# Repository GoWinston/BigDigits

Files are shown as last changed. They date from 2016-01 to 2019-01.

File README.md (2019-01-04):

# The Big Board

This is an Arduino powered system to allow the construction of giant seven segment displays, up to 50V 0.5A per segment.

The library workes with any Arduino using the SPI protocol, allowing a 4 digit display (32 segements) to be remotely connected via a single ethernet cable.

Two PCB designs are included, one with four digits on one board and another with a single digit per board.  

The hardware and library support four channels. 

<hr>

Boards are availible at OshPark <br>
4 Channel: https://oshpark.com/shared_projects/9ZOlH1Lw <br>
Digikey parts list [here](https://github.com/GoWinston/BigDigits/blob/master/PCB's/4%20Digit%20PCB%20Materials%20Digikey.csv)<br>
<br>
1 Channel: https://oshpark.com/shared_projects/VTMd3b0f <br>
Digikey parts list [here](https://github.com/GoWinston/BigDigits/blob/master/PCB's/1%20Digit%20PCB%20Materials%20Digikey.csv)<br>

<hr>

Connect to the Arduino with a standard ethernet cable and the SparkFun RJ45 Breakout <br>
https://www.sparkfun.com/products/716 <br>
<br>
```
Ethernet | Arduino | Assignment
    1         13      Clock - SCK - SHCP
    2         11      Data - MOSI - DS
    3         9       Digit D  X---  Thousands
    4         6       Digit A  ---X  Units
    5         8       Digit C  -X--  Hundreds
    6         7       Digit B  --X-  Tens
    7         +5      VCC
    8         GND     GND
```
<hr>

The power for the big displays goes directly into the PCBs and is seperate from the logic power on the Arduino which travels over the ethernet cable<br>
<br>
Power each segement from V+ --> LED segment lights --> Control Board <br>
<hr>

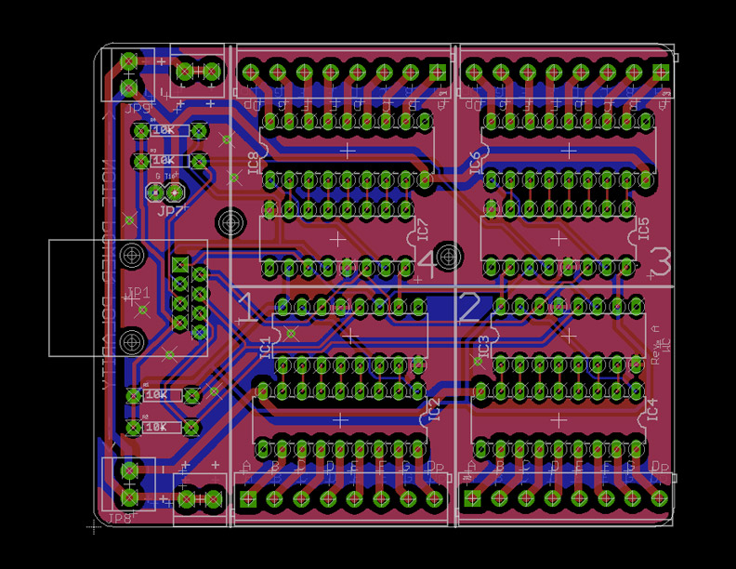
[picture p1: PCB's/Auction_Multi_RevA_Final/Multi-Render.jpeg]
4 channel board


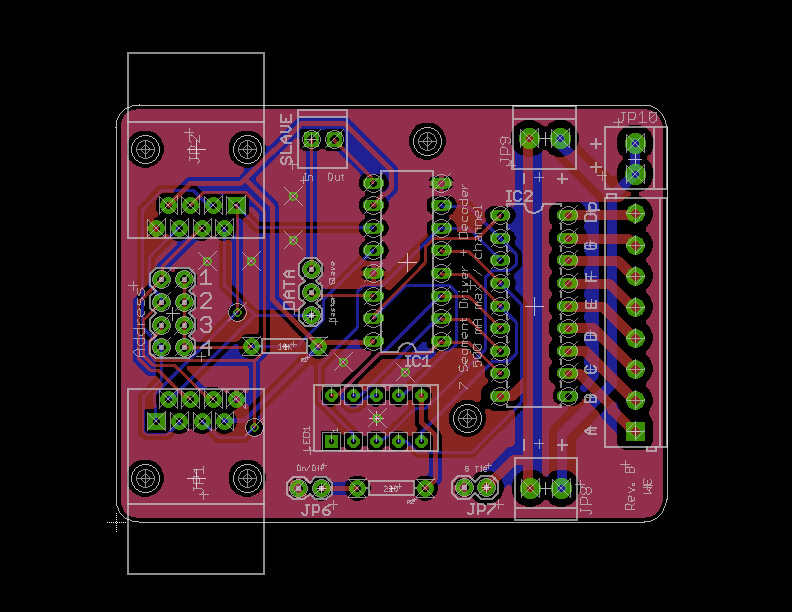
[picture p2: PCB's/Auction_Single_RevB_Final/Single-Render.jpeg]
1 channel board


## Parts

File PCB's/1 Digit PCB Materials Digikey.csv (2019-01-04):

Manufacturer Part Number | Manufacturer | Digi-Key Part Number | Customer Reference | Reference Designator | Packaging | Part Status | Quantity | Unit Price | Extended Price | Quantity Available | Mfg Std Lead Time | Description | RoHS Status | Lead Free Status | REACH Status | US Tariff Status
SN74HC595N | Texas Instruments | 296-1600-5-ND | IC1 |  | Tube | Active | 1 | 0.53000 | $0.53 | 27007 | 8 Weeks | IC 8-BIT SHIFT REGISTER 16-DIP | RoHS Compliant | Lead free | REACH Unaffected
ULN2803A | STMicroelectronics | 497-2356-5-ND | IC2 |  | Tube | Active | 1 | 1.19000 | $1.19 | 48108 | 28 Weeks | TRANS 8NPN DARL 50V 0.5A 18DIP | RoHS Compliant | Lead free | Not Available
CFR-25JB-52-10K | Yageo | 10KQBK-ND | 10k Resistor |  | Bulk | Active | 1 | 0.10000 | $0.10 | 395176 | 16 Weeks | RES 10K OHM 1/4W 5% AXIAL | RoHS Compliant | Lead free | REACH Unaffected
54602-908LF | Amphenol ICC (FCI) | 609-1046-ND | Ethernet Jack |  | Bulk | Active | 2 | 0.60000 | $1.20 | 101891 | 6 Weeks | CONN MOD JACK 8P8C R/A UNSHLD | RoHS Compliant | Lead free | Not Available
PH2-230/120-081 | On Shore Technology Inc. | PH2-230/120-081-ND | Address Selector |  | Bulk | Active | 1 | 0.40000 | $0.40 | 26 | 12 Weeks | CONN HEADER VERT 8POS 2.54MM | RoHS Compliant | Lead free | REACH Unaffected | Tariff Applied
61300311121 | Wurth Electronics Inc. | 732-5316-ND | Slave Master Selector |  | Bag | Active | 1 | 0.13000 | $0.13 | 142616 | 14 Weeks | CONN HEADER VERT 3POS 2.54MM | RoHS Compliant | Lead free | REACH Unaffected
282834-2 | TE Connectivity AMP Connectors | A98333-ND | Selector Pins Display Ground Tie |  | Box | Active | 2 | 0.88000 | $1.76 | 28602 | 21 Weeks | TERM BLK 2P SIDE ENT 2.54MM PCB | RoHS Compliant | Lead free | Not Available
382811-8 | TE Connectivity AMP Connectors | A26228-ND | Shunts for pins |  | Bulk | Active | 4 | 0.00000 | $0.00 | 57180 | 4 Weeks | CONN SHUNT 2POS OPEN 2.54MM | RoHS Compliant | Lead free | Not Available
HDSP-C3E3 | Broadcom Limited | 516-3177-5-ND | Seven Segment Display |  | Tube | Active | 1 | 0.00000 | $0.00 | 0 | 12 Weeks | DISPLAY 0.36 SGL DGT CC RED TH | RoHS Compliant | Lead free | REACH Unaffected | Tariff Applied
OSTTE080104 | On Shore Technology Inc. | ED2746-ND | Display Segment Connectors (optional) |  | Bulk | Active | 1 | 1.64000 | $1.64 | 7452 | 12 Weeks | TERM BLK 8POS SIDE ENT 3.5MM PCB | RoHS Compliant | Lead free | REACH Unaffected | Tariff Applied
1984617 | Phoenix Contact | 277-1721-ND | Power Connectors (optional) |  | Box | Active | 3 | 0.48000 | $1.44 | 72569 | 4 Weeks | TERM BLK 2POS SIDE ENT 3.5MM PCB | RoHS Compliant | Lead free | Not Available
A 16-LC-TT | Assmann WSW Components | AE9992-ND | Sockets for SHIFT REGISTER (optional) |  | Tube | Active | 1 | 0.25000 | $0.25 | 46264 | 20 Weeks | CONN IC DIP SOCKET 16POS TIN | RoHS Compliant | Lead free | REACH Unaffected | Tariff Eligible
ED18DT | On Shore Technology Inc. | ED3047-5-ND | Socket for ULN2803A (optional no high current) |  | Tube | Active | 1 | 0.23000 | $0.23 | 12504 | 12 Weeks | CONN IC DIP SOCKET 18POS TIN | RoHS Compliant | Lead free | REACH Unaffected | Tariff Applied
282834-2 | TE Connectivity AMP Connectors | A98333-ND | Connector for Slave Data Input (optional) |  | Box | Active | 1 | 0.88000 | $0.88 | 28602 | 21 Weeks | TERM BLK 2P SIDE ENT 2.54MM PCB | RoHS Compliant | Lead free | Not Available
CFR-25JB-52-220R | Yageo | 220QBK-ND | 220ohm for micro display |  | Bulk | Active | 1 | 0.10000 | $0.10 | 144243 | 16 Weeks | RES 220 OHM 1/4W 5% AXIAL | RoHS Compliant | Lead free | REACH Unaffected

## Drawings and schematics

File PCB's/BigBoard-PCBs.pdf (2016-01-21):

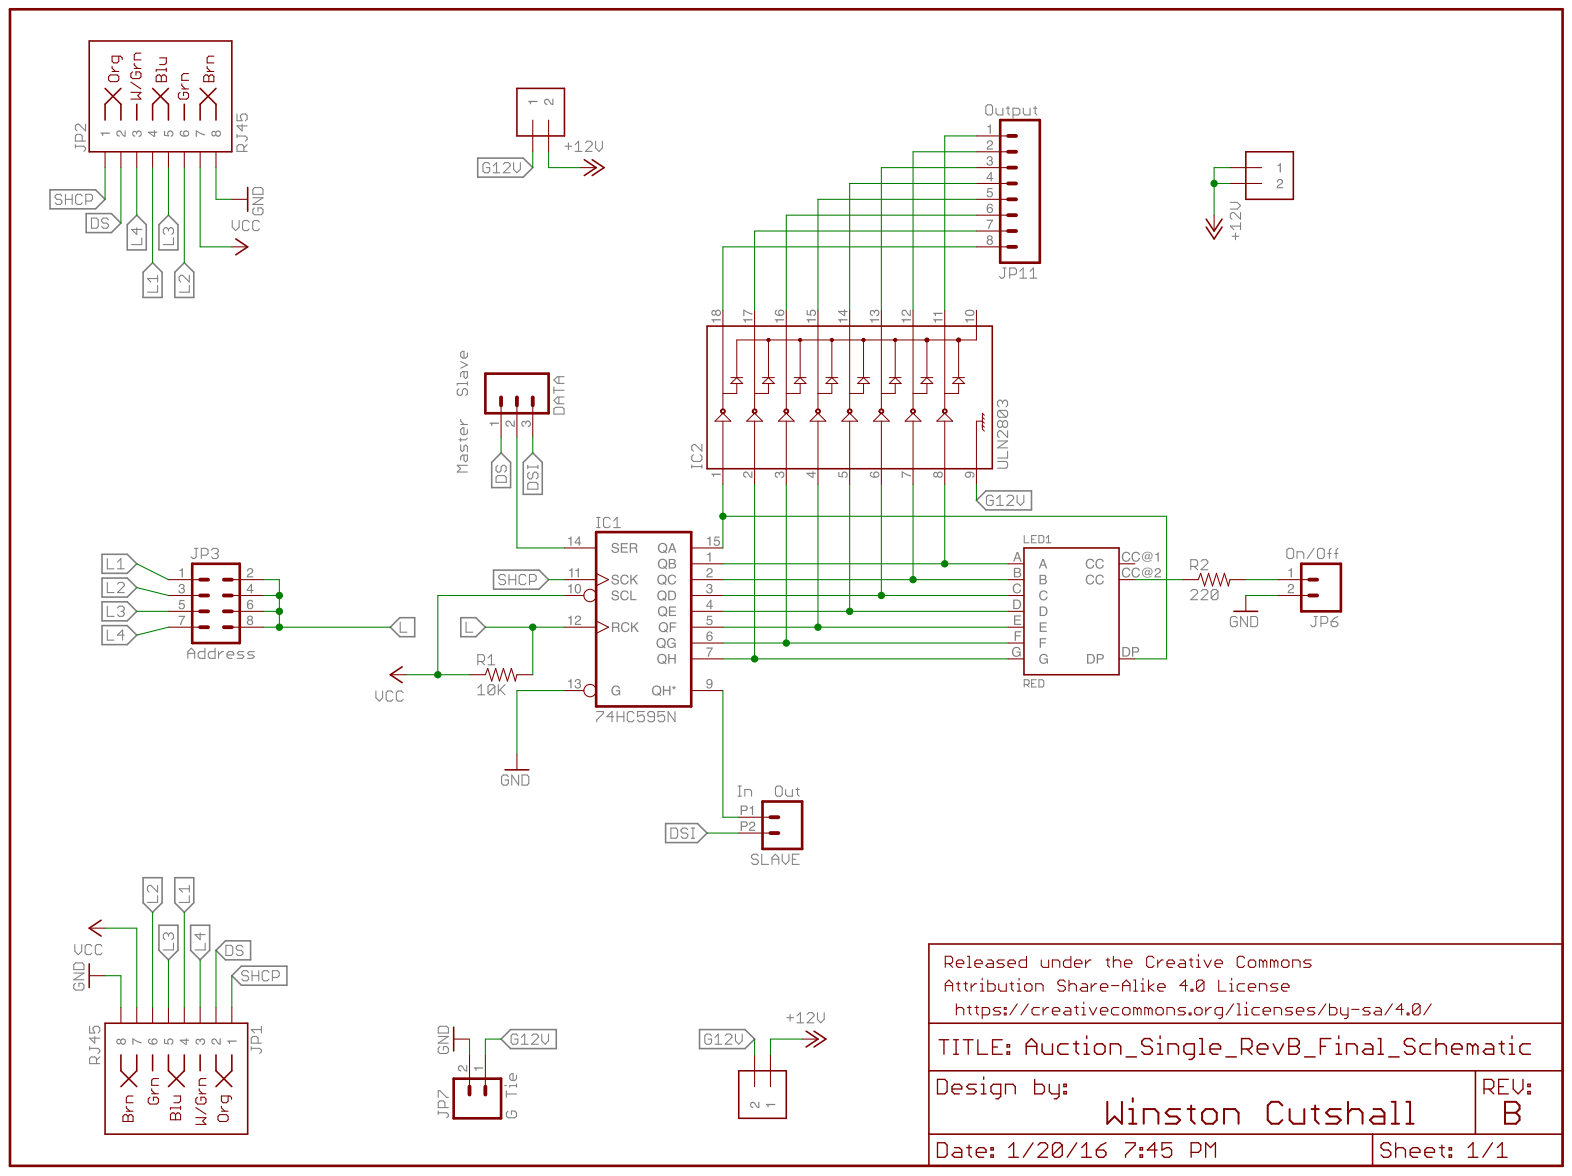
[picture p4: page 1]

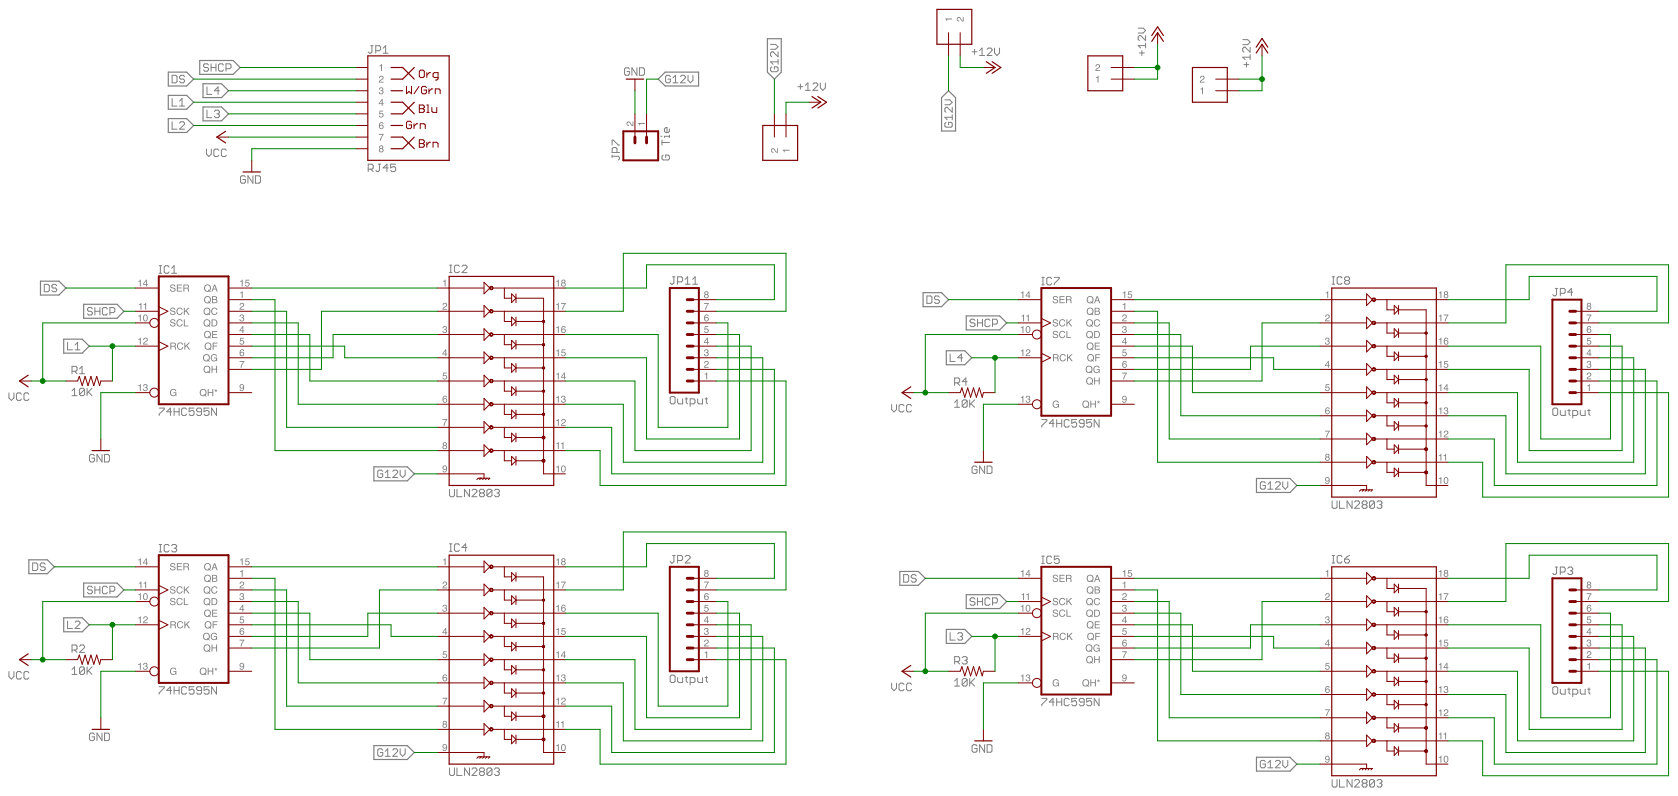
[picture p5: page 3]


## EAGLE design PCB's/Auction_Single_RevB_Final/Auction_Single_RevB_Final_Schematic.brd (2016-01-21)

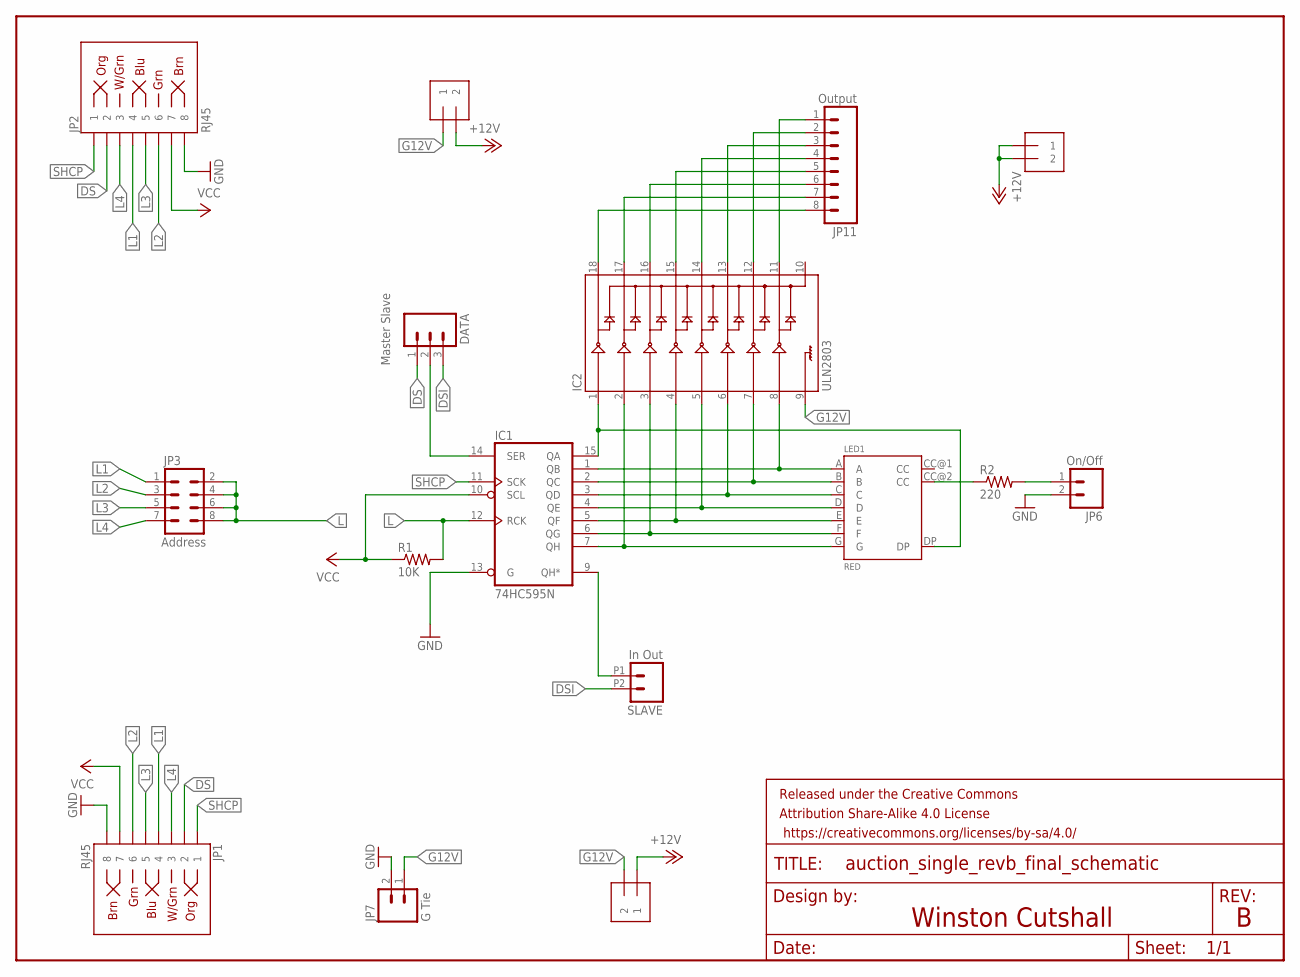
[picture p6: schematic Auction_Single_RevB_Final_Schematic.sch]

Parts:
DATA: Master Slave; 1X03; MPN 2211S-03G
FRAME1: FRAME-LETTER; CREATIVE_COMMONS
IC1: 74HC595N; DIL16; MPN SN74HC595N
IC2: ULN2803; DIL18; MPN ULN2803A
JP1, JP2: RJ45; RJ45-8; MPN 54602-908LF
JP3: Address; 2X4; MPN M20-9980446
JP6: On/Off; 1X02; MPN 2211S-02G
JP7: G Tie; 1X02; MPN 2211S-02G
JP8, JP9, JP10: 1X2-3.5MM; MPN 1776275-2
JP11: Output; SCREWTERMINAL-3.5MM-8; MPN 20020327-C081B01LF
LED1: RED; HDSP-C3X3
R1: 10K; AXIAL-0.3EZ; MPN MCF 0.25W 10K
R2: 220; AXIAL-0.3EZ; MPN MCF 0.25W 220R
SLAVE: In Out; 1X02_2.54_SCREWTERM; MPN 282834-2

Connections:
+12V: JP8.1, JP9.2, JP10.1, JP10.2
A: IC1.1 (QB), IC2.8, LED1.A
AA: IC2.11, JP11.1
B: IC1.2 (QC), IC2.7, LED1.B
BB: IC2.12, JP11.2
C: IC1.3 (QD), IC2.6, LED1.C
CC: IC2.13, JP11.3
D: IC1.4 (QE), IC2.5, LED1.D
DD: IC2.14, JP11.4
DIP_SEG: JP6.1, R2.P$2 (2)
DP: IC1.15 (QA), IC2.1, LED1.DP
DPA: IC2.18, JP11.8
DS: DATA.1, JP1.2, JP2.2
DSF: DATA.2, IC1.14 (SER)
DSI: DATA.3, SLAVE.P2 (2)
E: IC1.5 (QF), IC2.4, LED1.E
EE: IC2.15, JP11.5
F: IC1.6 (QG), IC2.3, LED1.F
FF: IC2.16, JP11.6
G: IC1.7 (QH), IC2.2, LED1.G
G12V: IC2.9, JP7.1, JP8.2, JP9.1
GG: IC2.17, JP11.7
GND: IC1.8 (GND), IC1.13 (G), JP1.8, JP2.8, JP6.2, JP7.2
L: IC1.12 (RCK), JP3.2, JP3.4, JP3.6, JP3.8, R1.P$2 (2)
L1: JP1.4, JP2.4, JP3.1
L2: JP1.6, JP2.6, JP3.3
L3: JP1.5, JP2.5, JP3.5
L4: JP1.3, JP2.3, JP3.7
unnamed: LED1.CC@2 (CC), R2.P$1 (1)
unnamed: IC1.9 (QH*), SLAVE.P1 (1)
SHCP: IC1.11 (SCK), JP1.1, JP2.1
VCC: IC1.10 (SCL), IC1.16 (VCC), JP1.7, JP2.7, R1.P$1 (1)

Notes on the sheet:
Winston Cutshall

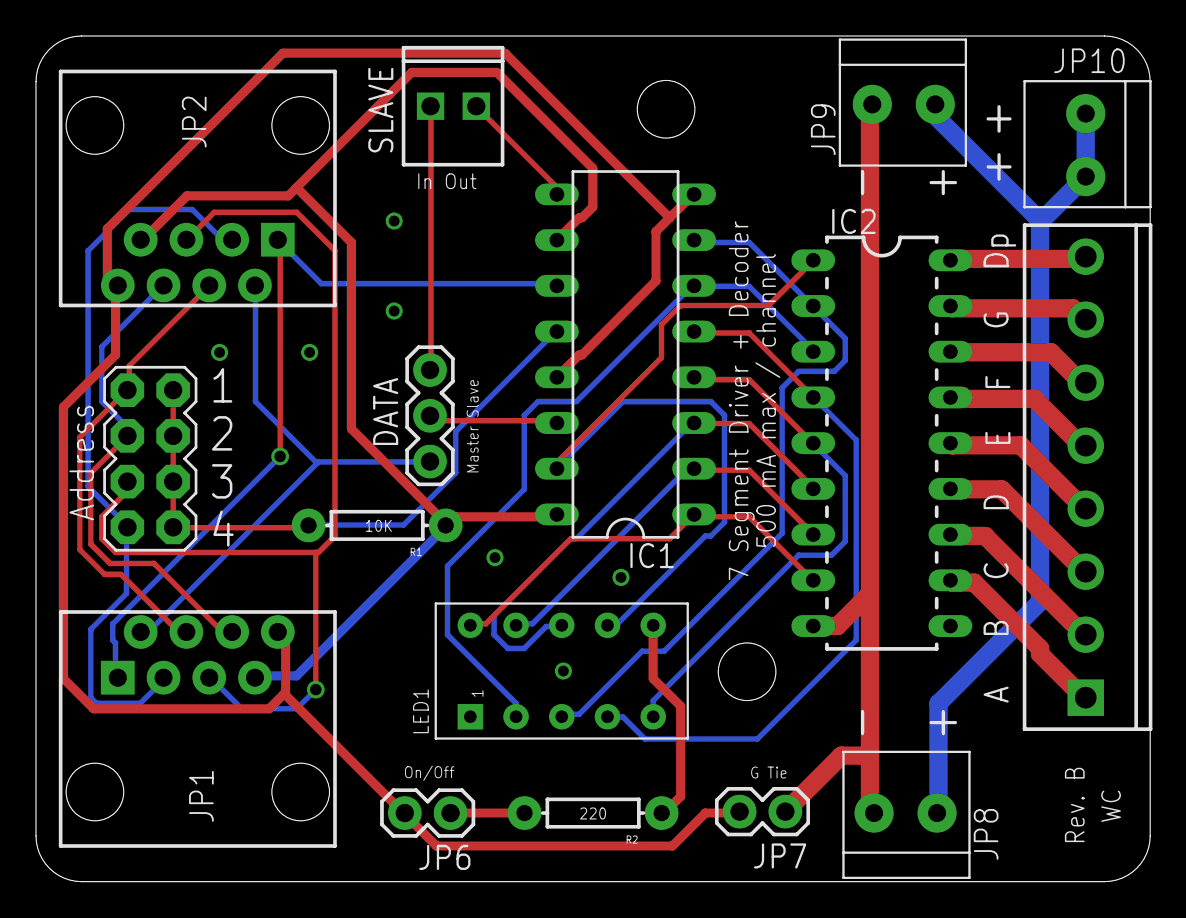
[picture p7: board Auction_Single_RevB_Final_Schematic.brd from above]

Board: 2 copper layers, 61.9 x 47.0 mm, 17 parts (0 on the bottom side), 32 nets.

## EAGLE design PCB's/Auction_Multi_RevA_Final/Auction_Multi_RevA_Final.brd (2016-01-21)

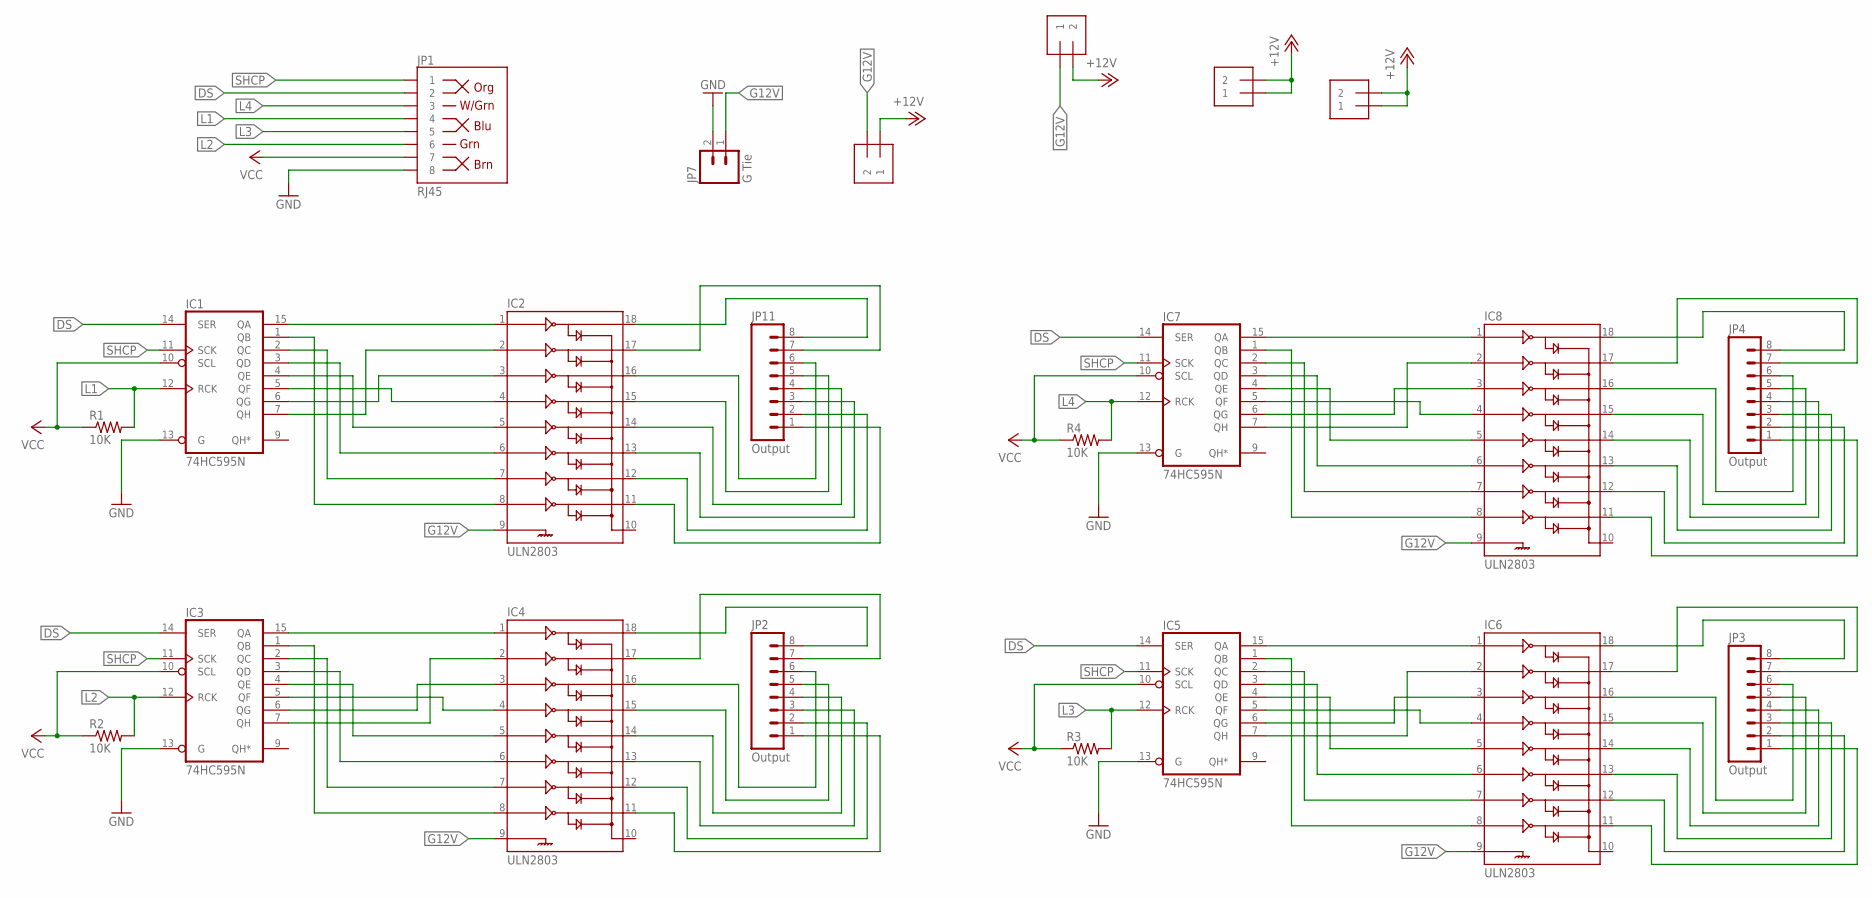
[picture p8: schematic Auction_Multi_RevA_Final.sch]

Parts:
IC1, IC3, IC5, IC7: 74HC595N; DIL16; MPN SN74HC595N
IC2, IC4, IC6, IC8: ULN2803; DIL18; MPN ULN2803A
JP1: RJ45; RJ45-8; MPN 54602-908LF
JP2, JP3, JP4, JP11: Output; SCREWTERMINAL-3.5MM-8; MPN 20020327-C081B01LF
JP5, JP8, JP9, JP10: 1X2-3.5MM; MPN 1776275-2
JP7: G Tie; 1X02; MPN 2211S-02G
R1, R2, R3, R4: 10K; AXIAL-0.3EZ; MPN MCF 0.25W 10K

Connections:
+12V: JP5.1, JP5.2, JP8.1, JP9.2, JP10.1, JP10.2
A: IC1.1 (QB), IC2.8
A3: IC7.1 (QB), IC8.8
AA: IC2.11, JP11.1
AA1: IC4.11, JP2.1
AA2: IC6.11, JP3.1
AA3: IC8.11, JP4.1
B3: IC7.2 (QC), IC8.7
BB: IC2.12, JP11.2
BB1: IC4.12, JP2.2
BB2: IC6.12, JP3.2
BB3: IC8.12, JP4.2
C3: IC7.3 (QD), IC8.6
CC: IC2.13, JP11.3
CC1: IC4.13, JP2.3
CC2: IC6.13, JP3.3
CC3: IC8.13, JP4.3
D3: IC7.4 (QE), IC8.5
DD: IC2.14, JP11.4
DD1: IC4.14, JP2.4
DD2: IC6.14, JP3.4
DD3: IC8.14, JP4.4
DP: IC1.15 (QA), IC2.1
DP1: IC3.15 (QA), IC4.1
DP2: IC5.15 (QA), IC6.1
DP3: IC7.15 (QA), IC8.1
DPA: IC2.18, JP11.8
DPA1: IC4.18, JP2.8
DPA2: IC6.18, JP3.8
DPA3: IC8.18, JP4.8
DS: IC1.14 (SER), IC3.14 (SER), IC5.14 (SER), IC7.14 (SER), JP1.2
E1: IC3.5 (QF), IC4.4
E2: IC5.5 (QF), IC6.4
E3: IC7.5 (QF), IC8.4
EE: IC2.15, JP11.5
EE1: IC4.15, JP2.5
EE2: IC6.15, JP3.5
EE3: IC8.15, JP4.5
F: IC1.6 (QG), IC2.3
F1: IC3.6 (QG), IC4.3
F2: IC5.6 (QG), IC6.3
F3: IC7.6 (QG), IC8.3
FF: IC2.16, JP11.6
FF1: IC4.16, JP2.6
FF2: IC6.16, JP3.6
FF3: IC8.16, JP4.6
G: IC1.7 (QH), IC2.2
G1: IC3.7 (QH), IC4.2
G2: IC5.7 (QH), IC6.2
G3: IC7.7 (QH), IC8.2
G12V: IC2.9, IC4.9, IC6.9, IC8.9, JP7.1, JP8.2, JP9.1
GG: IC2.17, JP11.7
GG1: IC4.17, JP2.7
GG2: IC6.17, JP3.7
GG3: IC8.17, JP4.7
GND: IC1.8 (GND), IC1.13 (G), IC3.8 (GND), IC3.13 (G), IC5.8 (GND), IC5.13 (G), IC7.8 (GND), IC7.13 (G), JP1.8, JP7.2
L1: IC1.12 (RCK), JP1.4, R1.P$2 (2)
L2: IC3.12 (RCK), JP1.6, R2.P$2 (2)
L3: IC5.12 (RCK), JP1.5, R3.P$2 (2)
L4: IC7.12 (RCK), JP1.3, R4.P$2 (2)
unnamed: IC3.4 (QE), IC4.5
unnamed: IC1.2 (QC), IC2.7
unnamed: IC1.4 (QE), IC2.5
unnamed: IC1.3 (QD), IC2.6
unnamed: IC1.5 (QF), IC2.4
unnamed: IC3.3 (QD), IC4.6
unnamed: IC3.2 (QC), IC4.7
unnamed: IC3.1 (QB), IC4.8
unnamed: IC5.1 (QB), IC6.8
unnamed: IC5.2 (QC), IC6.7
unnamed: IC5.3 (QD), IC6.6
unnamed: IC5.4 (QE), IC6.5
SHCP: IC1.11 (SCK), IC3.11 (SCK), IC5.11 (SCK), IC7.11 (SCK), JP1.1
VCC: IC1.10 (SCL), IC1.16 (VCC), IC3.10 (SCL), IC3.16 (VCC), IC5.10 (SCL), IC5.16 (VCC), IC7.10 (SCL), IC7.16 (VCC), JP1.7, R1.P$1 (1), R2.P$1 (1), R3.P$1 (1), R4.P$1 (1)

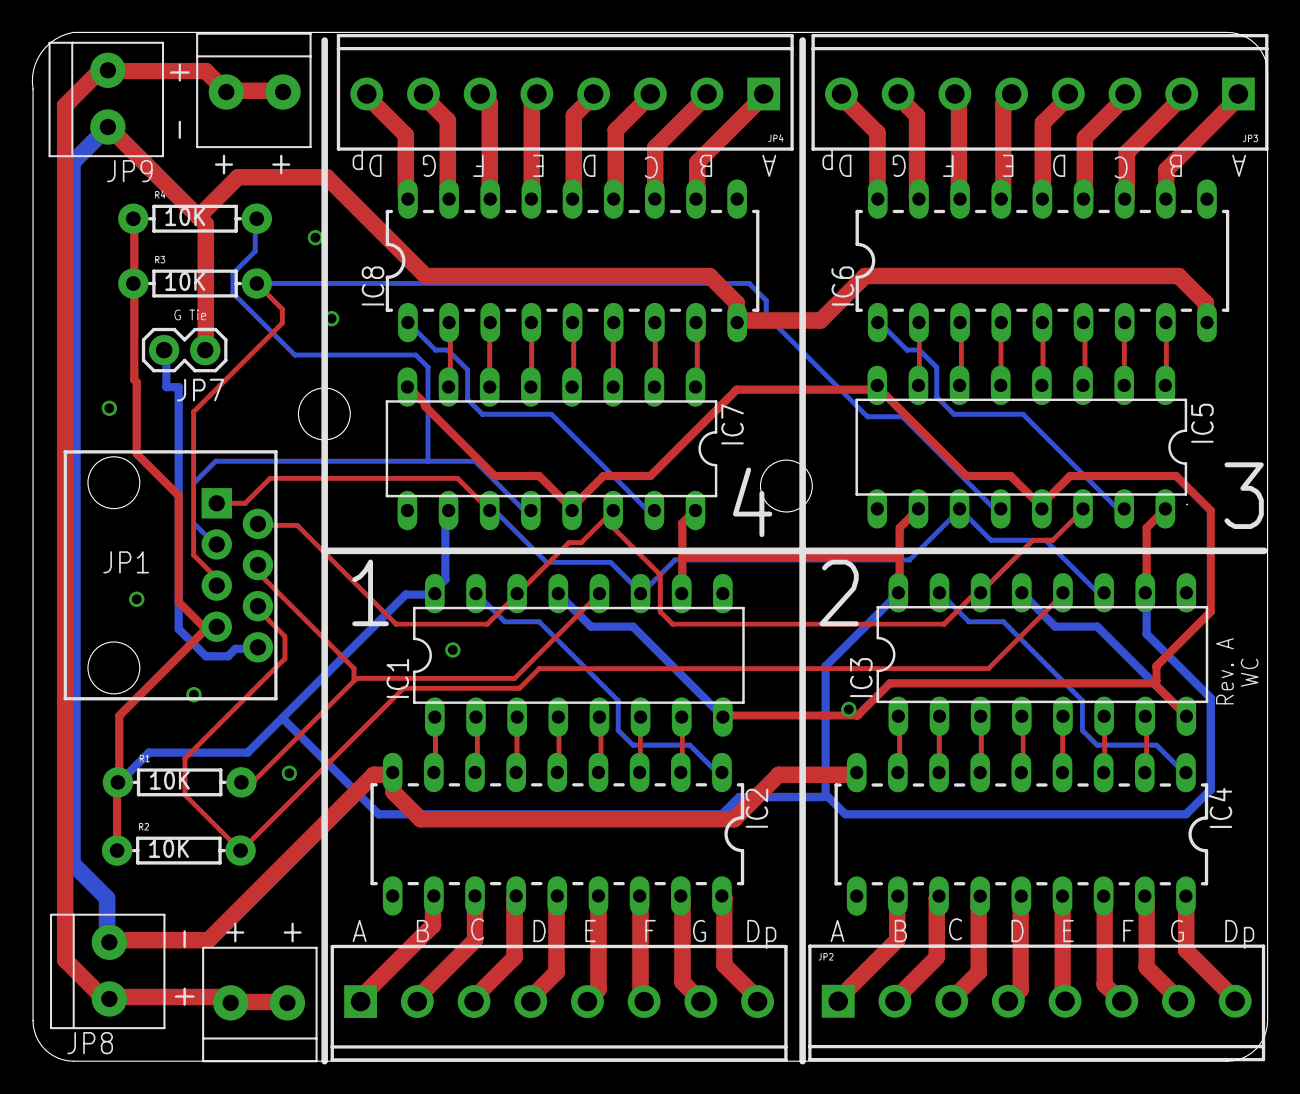
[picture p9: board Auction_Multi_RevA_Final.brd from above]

Board: 2 copper layers, 76.2 x 63.5 mm, 22 parts (0 on the bottom side), 74 nets.

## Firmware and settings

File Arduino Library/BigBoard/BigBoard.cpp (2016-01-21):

/*
*  BigBoard Library
*  
*  A library for rolling your own giant seven-segment display with the BigBoard PCB.
*  Get your own board at http://example.com
*  
*  Author	Winston Cutshall
*           http://example.com
*  
*  Date		10/29/15
*  Version	0.9 Beta
*  
*  Copyright	© Winston Cutshall, 2015
*  License	BSD license, all text above must be included in any redistribution
*/

#include "Arduino.h"
#include "BigBoard.h"

BigBoard::BigBoard (byte DigitA, byte DigitB, byte DigitC, byte DigitD, boolean clearZero) {
  _DigitA = DigitA;
  _DigitB = DigitB;
  _DigitC = DigitC;
  _DigitD = DigitD;
  _clearZero = clearZero;
}

void BigBoard::begin () {

  SPI.begin();

  // Latch initialization
  pinMode(_DigitA, OUTPUT); // ---X  Units
  pinMode(_DigitB, OUTPUT); // --X-  Tens
  pinMode(_DigitC, OUTPUT); // -X--  Hundreds
  pinMode(_DigitD, OUTPUT); // X---  Thousands
  // Latches Set High
  digitalWrite(_DigitA, HIGH);
  digitalWrite(_DigitB, HIGH);
  digitalWrite(_DigitC, HIGH);
  digitalWrite(_DigitD, HIGH);
}




/*****   CORE FUNCTION which actually puts stuff on the board   *****/

void BigBoard::displayChar ( byte where, byte what) {
    SPI.beginTransaction(SPISettings(25000000, MSBFIRST, SPI_MODE0));
    switch (where) {
      case 0: // ---X
        digitalWrite(_DigitA, LOW);
        _DataA = font(what);
        if (_DpA) {
          bitSet(_toTransfer, 0);
        }
        SPI.transfer(_toTransfer);
        digitalWrite(_DigitA, HIGH);
        break;
      case 1: // --X-
        digitalWrite(_DigitB, LOW);
        _DataB = font(what);
        if (_DpB) {
          bitSet(_toTransfer, 0);
        }
        SPI.transfer(_toTransfer);
        digitalWrite(_DigitB, HIGH);
        break;
      case 2: // -X--
        digitalWrite(_DigitC, LOW);
        _DataC = font(what);
        if (_DpC) {
          bitSet(_toTransfer, 0);
        }
        SPI.transfer(_toTransfer);
        digitalWrite(_DigitC, HIGH);
        break;
      case 3: // X---
        digitalWrite(_DigitD, LOW);
        _DataD = font(what);
        if (_DpD) {
          bitSet(_toTransfer, 0);
        }
        SPI.transfer(_toTransfer);
        digitalWrite(_DigitD, HIGH);
        break;
    }
    SPI.endTransaction();
}



/*****   Functions for displaying numbers   *****/

void BigBoard::displayNum (int number) {
  byte payloadA;
  byte payloadB;
  byte payloadC;
  byte payloadD;
  if (number > 9999 || number < -999) {
    displayWord ("-err");
  }
  else {
    int thousands = abs(number) / 1000;
    if (number < 0 ) {
      payloadD = 45;
    }
    else if ( number > 999) {
      payloadD = thousands;
    }
    else if (_clearZero && number < 1000) {
      payloadD = 36;
    }
    else {
      payloadD = 0;
    }
    int hundreds = (abs(number) - (thousands * 1000)) / 100;
    if ( abs(number) > 99) {
      payloadC = hundreds;
    }
    else if (abs(number) < 100) {
      if (_clearZero) {
        payloadC = 36;
      }
      else {
        payloadC = 0;
      }
    }
    int tens = (abs(number) - (thousands * 1000) - (hundreds * 100)) / 10;
    if ( abs(number) > 9) {
      payloadB = tens;
    }
    else if (abs(number) < 10) {
      if (_clearZero) {
        payloadB = 36;
      }
      else {
        payloadB = 0;
      }
    }
    int units = abs (number % 10);
    payloadA = units;

    displayChar (3, payloadD);
    displayChar (2, payloadC);
    displayChar (1, payloadB);
    displayChar (0, payloadA);
    
    _prevNum = number;
  }
}
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

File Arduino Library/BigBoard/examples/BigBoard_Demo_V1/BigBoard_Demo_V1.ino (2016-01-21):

/*
*  BigBoard Library Demo Sketch
*  
*  Some code for rolling your own giant seven-segment display with the BigBoard PCB.
*  Get your own board at http://example.com
*  
*  Author		Winston Cutshall
*           http://example.com
*  
*  Date		10/29/15
*  Version	0.9 Beta
*  
*  Copyright	© Winston Cutshall, 2015
*  License	BSD license, all text above must be included in any redistribution
*/


/*
These are the typical pin connections for using the BigBoard

Ethernet | Arduino | Assignment
    1         13      Clock - SCK - SHCP
    2         11      Data - MOSI - DS
    3         9       Digit D  X---  Thousands
    4         6       Digit A  ---X  Units
    5         8       Digit C  -X--  Hundreds
    6         7       Digit B  --X-  Tens
    7         +5      VCC
    8         GND     GND
*/

// include these two libraries to use the BigBoard
#include <SPI.h>
#include <BigBoard.h>

/*
 * Create an instance of the BigBoard
 * Setup variables are as follows:
 * DigitA = pin number for the rightmost digit - the units - index zero
 * DigitB = pin number for the tens - index one
 * DigitC = pin number for the hundreds - index two
 * DigitD = pin number for the thousands - index three
 * clearZero = boolean setting to remove leading zeros from numbers
*/

BigBoard tally (6, 7, 8, 9, true);

void setup() {

  // Initialize the instance
  tally.begin();

}// END SETUP

void loop() {

  // ******** The most basic and difficult way to display something ************//
  // display any character (location, value)
  // locations are indexed from the right and start at zero: A=0, B=1, C=2, D=3
  tally.displayChar (0, 117);  // 117 is "u" in ASCII
  delay (1000);

  // ******** Methods to display text ************//
  // NOTE: 4 characters or less

  // instead of coding each letter, just us a string
  // HINT:  USE ALL CAPS (all lower case characters will be converted to capitals)
  tally.displayWord ("LOOK");
  delay (1000);

  // and then get fancy
  tally.spinWord ("GOOD");
  delay (1000);

  // clears the display, but the Decimal Point (DP) channels are unchanged.
  tally.clear();
  delay (1000);

  // ******** Methods to display numbers ************//
  // NOTE: range is -999 to 9999

  // you could just give it a number
  tally.displayNum (1234);
  delay (1000);

  // or your could get fancy and spin the numbers
  // this one will spin clockwise because you're increasing from the previous value
  tally.spinNum (5678);
  delay (1000);

  // this one spins counterclockwise because it is lower than the previous number
  tally.spinNum (0);
  delay (1000);

  // clear everything - the display and DP's will all be off
  tally.reset();
  delay (1000);

  // ******** Methods to do visual effects ************//

  // spins all selected digits clockwise (seg D, seg C, seg B, seg A, reps, speed - lower is faster)
  tally.spinF (true, true, true, true, 10, 25);

  // spins all selected digits counterclockwise (seg D, seg C, seg B, seg A, reps, speed - lower is faster)
  tally.spinB (true, true, true, true, 10, 25);

  // blinks the display, not DP's.  (reps, speed - lower is faster)
  tally.flash (5, 100);

  // ******** Methods to toggle the decimal point channels ************//

  //Toggle the DP status (location, value) || locations:  DpA = 0, DpB = 1, DpC = 2, DpD = 3

  tally.setDP(0, true);
  tally.setDP(1, true);
  tally.setDP(2, true);
  tally.setDP(3, true);
  delay (1000);
  tally.setDP(0, false);
  tally.setDP(1, false);
  tally.setDP(2, false);
  tally.setDP(3, false);

  // re-sends all display data and DP data.  
  // Not required here perse, but another function to be aware of.
  tally.refresh();
  delay (1000);

  // ******** lets put it all together and make something nice for the kids************//
  tally.clear();
  delay (1000);
  tally.displayWord ("____");
  tally.flash (5, 100);
  tally.spinWord ("AC11");
  delay (500);
  tally.flash (5, 100);
  tally.spinWord ("____");
  tally.flash (5, 100);
  tally.clear ();
  delay (1000);


}// END LOOP


/*
Here are the numbers to use to call a letter with the displayChar function:

Character   Number
    0       0 or 48
    1       1 or 49
    2       2 or 50
    3       3 or 51
    4       4 or 52
    5       5 or 53
    6       6 or 54
    7       7 or 55
    8       8 or 56
    9       9 or 57
Segment A   20
Segment B   21
Segment C   22
Segment D   23
Segment E   24
Segment F   25
Segment G   26
 (blank)    36
    -       45
    A       65 or 97
    B       66 or 98
    C       67 or 99
    D       68 or 100
    E       69 or 101
    F       70 or 102
    G       71 or 103
    H       72 or 104
    I       73 or 105
    J       74 or 106
    K       75 or 107
    L       76 or 108
    M       77 or 109
    N       78 or 110
    O       79 or 111
    P       80 or 112
    Q       81 or 113
    R       82 or 114
    S       83 or 115
    T       84 or 116
    U       85 or 117
    V       86 or 118
    W       87 or 119
    X       88 or 120
    Y       89 or 121
    Z       90 or 122
    _       95
*/

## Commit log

2016-01-21 Uploading Source Files
    [Auction_Multi_RevA_Final.brd, Auction_Multi_RevA_Final.sch, Auction_Single_RevB_Final.brd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]
2016-01-21 updating files
    [Auction_Single_RevB_Final.brd, Auction_Single_RevB_Final.sch]
2016-01-21 Updating PCB Files

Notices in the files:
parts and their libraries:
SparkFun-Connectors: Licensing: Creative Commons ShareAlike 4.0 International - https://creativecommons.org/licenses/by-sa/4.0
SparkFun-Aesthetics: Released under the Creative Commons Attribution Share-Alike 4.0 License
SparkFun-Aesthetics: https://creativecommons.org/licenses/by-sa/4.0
